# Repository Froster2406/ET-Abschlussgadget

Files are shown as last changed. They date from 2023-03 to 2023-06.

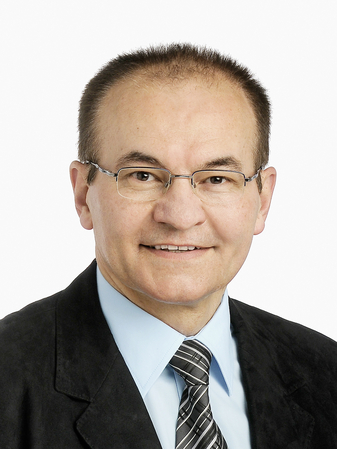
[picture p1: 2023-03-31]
Hardware/UrsRoethlisberger.jpeg

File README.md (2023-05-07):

# HS20-23 ET Abschlussgadget

Als Teil der Abschlusszeitung gibt es auch dieses Jahr wieder ein kleines Gadget kostenfrei dazu. Ganz im Namen des Überthemas "ET im PRENpunkt" mit der Anlehung an "Familien im Brennpunkt", kannst auch Du herausfinden, wie viel ET in Dir steckt. Aber nur wenn Du so asozial wie ein ET'ler bist, schaltet sich die geheime Zusatzfunktion frei.

## Verwendung

* Beiligende Batterie einlegen
* Schalter auf Platine in ON-Zustand versetzten
* Finger auf "Drück mich!" legen
* Anzeige ablesen

<details>
<summary>only for real engineers</summary>
<br>
You deem yourself a true engineer? Great!<br>
Tag along as we dive deeper into how you can reprogram the microcontroller. <br>

## general information
* [Reference Manual](https://ww1.microchip.com/downloads/aemDocuments/documents/MCU08/ProductDocuments/DataSheets/ATtiny212-214-412-414-416-DataSheet-DS40002287A.pdf)
* There are two pins (J1 & J2) on the side of the PCB than can be freely addressed, without interfering with the main functionality of the board

## preresquisites
* USB to serial converter | USB to TTL converter <br>
`Any converter (3.3V or 5V) off of Aliexpress, Ebay, Mouser, etc. will do.`
* 1kOhm resistor <br>
* Wires to connect the PCB to the converter <br>
* [Microchip Studio](https://www.microchip.com/en-us/tools-resources/develop/microchip-studio) <br>
* [Python](https://www.python.org/downloads/) installed on your machine <br>
* Python package: [pymcuprog](https://pypi.org/project/pymcuprog/) <br>
`pip install pymcuprog`<br>

## wiring diagram 
https://github.com/microchip-pic-avr-tools/pymcuprog#serial-port-updi-pyupdi

## reprogramming
* Connect the PCB to the USB to serial converter according to the wiring diagram
* Adjust the code to your liking and build it with F7
* Navigate to the python-programmer script <br>
`cd <YOUR_PATH>\ET-Abschlussgadget\Software\Programmer Python`
* Run the programming command <br>
`python attiny414.py <COM_PORT> <ABSOLUTE_PATH_TO_HEX_FILE_YOU_COMPILED_WITH_MICROCHIP_STUDIO>` <br>
*COM_PORT: If unknown, the available ones will be printed in the console*

* Power cycle the PCB

</details>

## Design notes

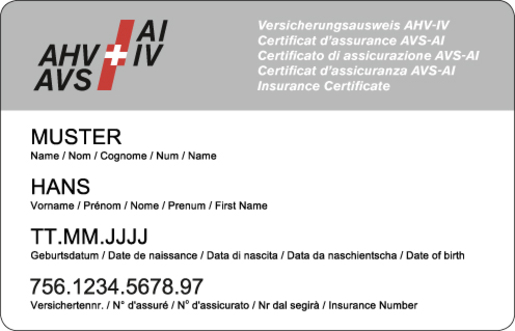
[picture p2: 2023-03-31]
Hardware/AHVAusweisMuster.jpg

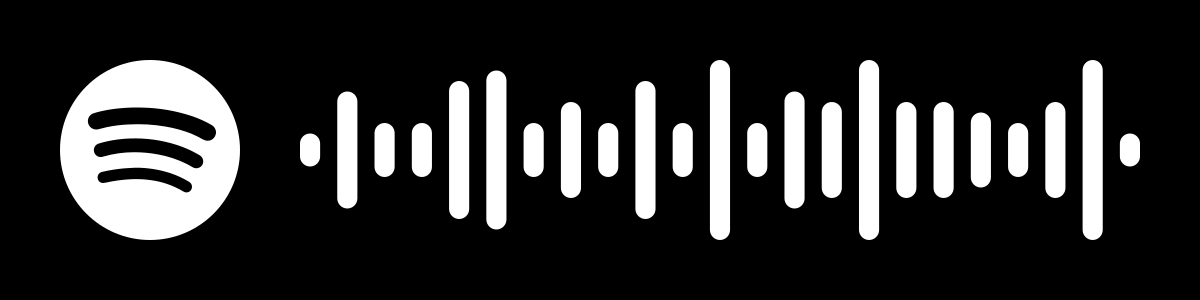
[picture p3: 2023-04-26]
Hardware/Spotify_Code.png

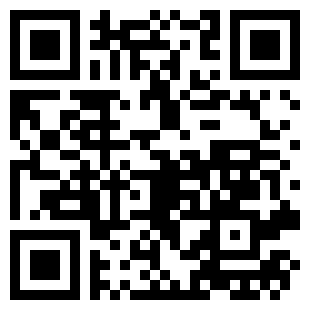
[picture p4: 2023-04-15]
Hardware/QR_Repo.png

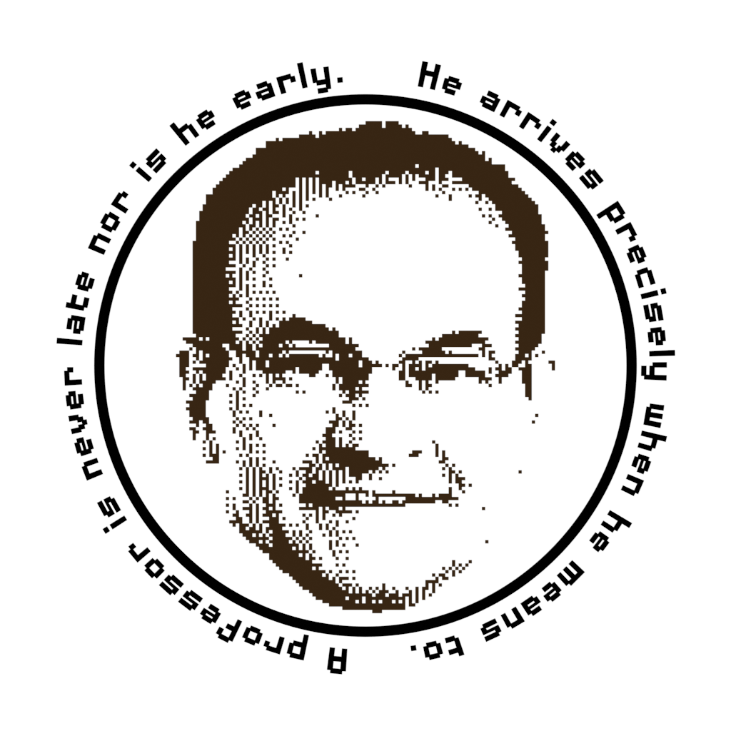
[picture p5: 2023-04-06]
Hardware/Rothli_Sticker_1.png

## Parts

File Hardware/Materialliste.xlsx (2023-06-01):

Typ | Link
MCU | https://www.lcsc.com/product-detail/Microcontroller-Units-MCUs-MPUs-SOCs_Microchip-Tech-ATTINY414-SSNR_C189365.html
CR2032 Battery holder | https://www.lcsc.com/product-detail/span-style-background-color-ff0-Battery-span-Connectors_Q-J-C70373_C70373.html
IR LED | https://www.lcsc.com/product-detail/Infrared-IR-LEDs_XSSY-XS-IR04A05-802_C5205266.html
LED Rot | https://www.lcsc.com/product-detail/Light-Emitting-Diodes-span-style-background-color-ff0-LED-span_XINGLIGHT-XL-1608SURC-06_C965799.html
Switch | https://www.lcsc.com/product-detail/span-style-background-color-ff0-Slide-span-Switches_SHOU-HAN-MSK12CO2-SZ_C2681568.html
100nF Cap | https://www.lcsc.com/product-detail/Multilayer-Ceramic-Capacitors-MLCC-SMD-SMT_CCTC-TCC0603X7R104K500CT_C282519.html
560 Ohm Resistor | https://www.lcsc.com/product-detail/Chip-Resistor-Surface-Mount_UNI-ROYAL-Uniroyal-Elec-0603WAJ0561T5E_C25247.html
N-MOSFET | https://www.lcsc.com/product-detail/MOSFETs_YONGYUTAI-SI2302_C2891732.html
1M Ohm Resistor | https://www.lcsc.com/product-detail/Chip-Resistor-Surface-Mount_Sunway-SC0603F1004F2BNRH_C3152128.html

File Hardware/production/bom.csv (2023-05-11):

Designator | Footprint | Quantity | Value | LCSC Part #
BT1 | BAT-SMD_CR2032-3V | 1 | 3V | C70373
C1 | C0603 | 1 | 100nF | C38141
D1 | XS-IR04A05-802 | 1 | LED_Ir | C396649
D2, D3, D4, D5, D6 | LED0603-RD_RED | 5 | LED_Red | C965799
J1, J2 | TestPoint_Pad_D2.0mm | 2 | EXTCLK
J3 | TestPoint_Pad_D1.0mm | 1 | PB0
J4 | TestPoint_Pad_D1.0mm | 1 | PB1
J5 | TestPoint_Pad_D2.0mm | 1 | UPDI / RESET
Q2 | SOT-23-3_L2.9-W1.3-P1.90-LS2.4-BR | 1 | SI2302_C2891732 | C2891732
R2, R3, R4, R5, R6, R7 | 0603 | 6 | 560 | C5140946
R8 | 0603 | 1 | 1M | C5140946
SW1 | SW-TH_MSK12C02 | 1 | ON/OFF | C2681568
TP1 | TestPoint_Pad_4.0x4.0mm | 1 | Capacitive Pad
U1 | SOIC-14_L8.7-W3.9-P1.27-LS6.0-BL | 1 | ATtiny414-SS | C189365

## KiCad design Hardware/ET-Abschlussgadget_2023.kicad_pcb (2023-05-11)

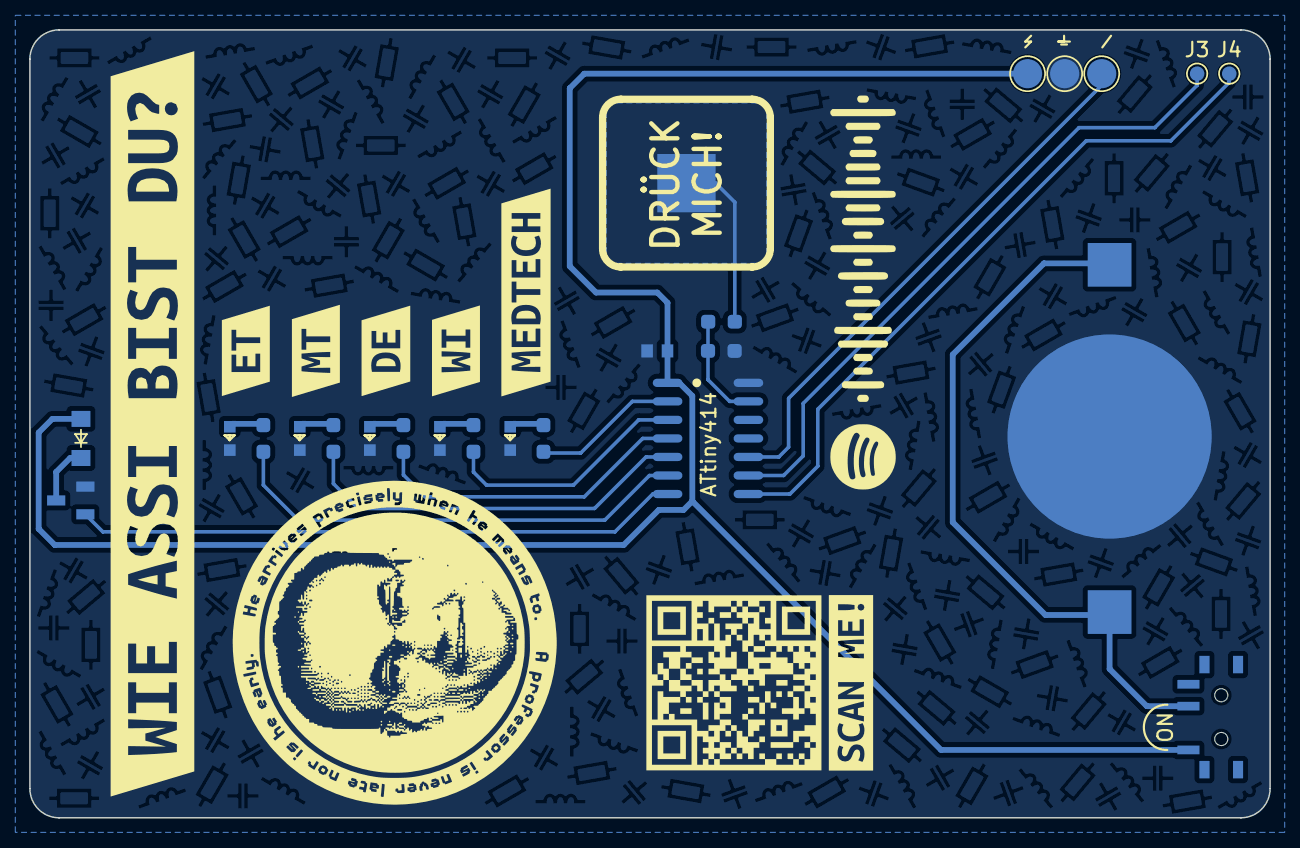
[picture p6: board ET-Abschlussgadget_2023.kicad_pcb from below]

Board: 2 copper layers, 85.0 x 54.0 mm, 31 parts (31 on the bottom side), 20 nets.

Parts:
BT1: 3V; BAT-SMD_CR2032-3V
C1: 100nF; C0603
D1: LED_Ir; XS-IR04A05-802
D2, D3, D4, D5, D6: LED_Red; LED0603-RD_RED
J1, J2: EXTCLK; TestPoint_Pad_D2.0mm
J3: PB0; TestPoint_Pad_D1.0mm
J4: PB1; TestPoint_Pad_D1.0mm
J5: UPDI / RESET; TestPoint_Pad_D2.0mm
Q2: SI2302_C2891732; SOT-23-3_L2.9-W1.3-P1.90-LS2.4-BR
R2, R3, R4, R5, R6, R7: 560; R_0603_1608Metric_Pad0.98x0.95mm_HandSolder
R8: 1M; R_0603_1608Metric_Pad0.98x0.95mm_HandSolder
SW1: ON/OFF; SW-TH_MSK12C02
TP1: Capacitive Pad; TestPoint_Pad_4.0x4.0mm
U1: ATtiny414-SS; SOIC-14_L8.7-W3.9-P1.27-LS6.0-BL
kibuzzard-642F12C7: G***; kibuzzard-642F12C7
kibuzzard-642F12D5: G***; kibuzzard-642F12D5
kibuzzard-642F12E3: G***; kibuzzard-642F12E3
kibuzzard-642F12EF: G***; kibuzzard-642F12EF
kibuzzard-642F1274: G***; kibuzzard-642F1274
kibuzzard-642F1300: G***; kibuzzard-642F1300
kibuzzard-64480F6A: G***; kibuzzard-64480F6A

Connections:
/Cap_Pad: R5.2, TP1.1
/Cap_Pad / ADC1: R5.1, R8.2, U1.13 (PA3)
/LED 1: R2.2, U1.6 (PB3)
/LED 2: R3.1, U1.5 (PA7)
/LED 3: R4.1, U1.4 (PA6)
/LED 4: R6.2, U1.3 (PA5)
/LED 5: R7.2, U1.2 (PA4)
/LED IR: Q2.1 (G), U1.7 (PB2)
/UPDI / RESET: J5.1, U1.10 (~RESET/PA0)
GND: BT1.2 (-), C1.2, D2.1 (K), D3.1 (K), D4.1 (K), D5.1 (K), D6.1 (K), J2.1, Q2.2 (S), R8.1, U1.14 (GND)
unnamed: BT1.1 (+), SW1.2 (B)
unnamed: D1.1 (K), Q2.3 (D)
unnamed: D2.2 (A), R2.1
unnamed: D3.2 (A), R3.2
unnamed: D4.2 (A), R4.2
unnamed: D5.2 (A), R6.1
unnamed: D6.2 (A), R7.1
unnamed: J3.1, U1.9 (PB0)
unnamed: J4.1, U1.8 (PB1)
VCC: C1.1, D1.2 (A), J1.1, SW1.1 (A), U1.1 (VCC)

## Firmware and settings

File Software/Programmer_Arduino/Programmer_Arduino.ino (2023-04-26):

/**************************************************
 * TPI programmer for ATtiny10
 * (possibly 4,5,9 as well)
 * Make the connections as shown below.
 * 
 * To use:
 *  - Upload to arduino and power off
 *  - Connect ATtiny10 as shown
 *  - Power on and open the serial monitor
 *  - If things are working so far you should
 *    see "NVM enabled" and "ATtiny10 connected".
 *  - Input one-letter commands via serial monitor:
 *    D = dump memory. Displays all current memory
 *        on the chip
 *    E = erase chip. Erases all program memory
 *    R = read program. After sending this command
 *        you have 20 seconds to copy and paste the
 *        entire contents of a .hex file into the
 *        serial monitor and send. You can do the
 *        whole file at once. If it was successful,
 *        you should see "program received".
 *    P = write program. After reading the program
 *        with the R command, use this to write the
 *        program to the ATtiny10.
 *    V = verify. Verifies that the program was
 *        written correctly. If not, it will display
 *        the errors.
 *    F = finish. not necessary, but this disables
 *        further access until the arduino is reset
 *    S = set fuse. follow the instructions to set
 *        one of the three fuses.
 *    C = clear fuse. follow the instructions to clear
 *        one of the three fuses.
 *  - Finally, power off the arduino and remove the
 *    Attiny10
 *                                                *
 * Arduino                 ATtiny10               *
 * ----------+          +----------------         *
 * (SS#)  10 |--[R]-----| 6 (RESET#/PB3)          *
 *           |          |                         *     
 * (MOSI) 16 |--[R]--+--| 1 (TPIDATA/PB0)         *
 *           |       |  |                         *
 * (MISO) 14 |--[R]--+  |                         *
 *           |          |                         *     
 * (SCK)  15 |--[R]-----| 3 (TPICLK/PB1)          *
 * ----------+          +----------------         *
 *                                                *
 *  -[R]-  =  a few kOhm resistor                 *
 *                                                *
 *  this picture : 2011/12/08 by pcm1723          *
 *                                                *
 * thanks to pcm1723 for tpitest.pde upon which   *
 * this is based                                  *
 **************************************************/
  
#include <SPI.h>
#include "pins_arduino.h"

#define SS 10

// define the instruction set bytes
#define SLD    0x20
#define SLDp   0x24
#define SST    0x60
#define SSTp   0x64
#define SSTPRH 0x69
#define SSTPRL 0x68
// see functions below ////////////////////////////////
// SIN  0b0aa1aaaa replace a with 6 address bits   
// SOUT 0b1aa1aaaa replace a with 6 address bits 
// SLDCS  0b1000aaaa replace a with address bits 
// SSTCS  0b1100aaaa replace a with address bits 
///////////////////////////////////////////////////////
#define SKEY   0xE0
#define NVM_PROGRAM_ENABLE 0x1289AB45CDD888FFULL // the ULL means unsigned long long

#define NVMCMD 0x33
#define NVMCSR 0x32
#define NVM_NOP 0x00
#define NVM_CHIP_ERASE 0x10
#define NVM_SECTION_ERASE 0x14
#define NVM_WORD_WRITE 0x1D

// represents the current pointer register value
unsigned short adrs = 0x0000;

// used for storing a program file
uint8_t data[1024]; //program data
unsigned int progSize = 0; //program size in bytes

// used for various purposes
long startTime;
int timeout;
uint8_t b, b1, b2, b3;
boolean idChecked;

void setup(){
  pinMode(SS, OUTPUT);
  digitalWrite(SS, HIGH);
  
  // set up serial
  Serial.begin(115200); // you can change this if you want
  while(!Serial);
  Serial.println("Start");
  Serial.print("SS: ");
  Serial.println(SS);
  Serial.print("MOSI: ");
  Serial.println(MOSI);
  Serial.print("MISO: ");
  Serial.println(MISO);
  Serial.print("SCK: ");
  Serial.println(SCK);
  pinMode(SS, OUTPUT);
  pinMode(MOSI, OUTPUT);
  pinMode(SCK, OUTPUT);
  
  // set up SPI
  SPI.begin();
  SPI.setBitOrder(LSBFIRST);
  SPI.setDataMode(SPI_MODE0);
  SPI.setClockDivider(SPI_CLOCK_DIV32);
  
  // enter TPI programming mode
  digitalWrite(SS, LOW); // assert RESET on tiny
  delay(1); // t_RST min = 400 ns @ Vcc = 5 V
  
  SPI.transfer(0xff); // activate TPI by emitting
  SPI.transfer(0xff); // 16 or more pulses on TPICLK
  SPI.transfer(0xff); // while holding TPIDATA to "1"
  
  writeCSS(0x02, 0x04); // TPIPCR, guard time = 8bits (default=128)

  Serial.println("CSS");
  
  send_skey(NVM_PROGRAM_ENABLE); // enable NVM interface
  
  Serial.println("SKEY");
  // wait for NVM to be enabled
  /*while(1) {
    SPI.transfer(0x55);
  }*/
  
  while((readCSS(0x00) & 0x02) < 1){
    Serial.print(".");
  }
  Serial.println("NVM enabled");
  
  // initialize memory pointer register  
  setPointer(0x0000);
  
  timeout = 20000;
  idChecked = false;
} // end setup()

void loop(){
  if(!idChecked){
    checkID();
    idChecked = true;
  }
  // when ready, send ready signal '.' and wait
  //Serial.write('.');
  while(Serial.available() < 1){
    // wait
  }
  // the first byte is a command
  // 'R' = read program via serial onto the arduino
  // 'P' = program the ATtiny using the read program
  // 'V' = verify the program on the ATtiny
  // 'D' = dump memory to serial monitor
  // 'E' = erase chip. erases current program memory.(done automatically by 'P')
  // 'F' = finalize. Just disables NVM. Not necessary.
  // 'S' = set fuse
  // 'C' = clear fuse
  
  char comnd = Serial.read();
  if(comnd == 'D'){
    dumpMemory();
  }else if(comnd == 'R'){
    Serial.println("Paste hex contents");
    if(receiveProgram()){
      Serial.println("program received");
      delay(10);
      Serial.print("size: ");
      Serial.print(progSize);
      Serial.println("bytes");
    }
  }else if(comnd == 'P'){
    if(progSize > 0){
      writeProgram();
    }else{
      Serial.println("no program data read");
    }
  }else if(comnd == 'E'){
    eraseChip();
  }else if(comnd == 'V'){
    if(verifyProgram()){
      Serial.println("program verified: correct");
    }
  }else if(comnd == 'F'){
    finish();
    Serial.println("everything finished. unplug and disconnect wires");
    return;
  }else if(comnd == 'S'){
    setConfig(true);
  }else if(comnd == 'C'){
    setConfig(false);
  }else{
    Serial.println("received unknown command");
  }
}

//  print the register, SRAM, config and signature memory
void dumpMemory(){
  uint8_t i;
  // initialize memory pointer register 
  setPointer(0x0000);
  
  Serial.println("Current memory state:");
  // read the memory up to 0x4400
  while(adrs < 0x4400){
    // read the byte at the current pointer address
    // and increment address
    tpi_send_byte(SLDp);
    b = tpi_receive_byte(); // get data byte
    
    // read all the memory, but only print
    // the register, SRAM, config and signature memory
    if ((0x0000 <= adrs && adrs <= 0x005F) // register/SRAM
       |(0x3F00 <= adrs && adrs <= 0x3F01) // NVM lock bits
       |(0x3F40 <= adrs && adrs <= 0x3F41) // config
       |(0x3F80 <= adrs && adrs <= 0x3F81) // calibration
       |(0x3FC0 <= adrs && adrs <= 0x3FC3) // ID
       |(0x4000 <= adrs && adrs <= 0x43FF) ) { // program
      // print +number along the top
      if ((0x00 == adrs)
          |(0x3f00 == adrs) // NVM lock bits
          |(0x3F40 == adrs) // config
          |(0x3F80 == adrs) // calibration
          |(0x3FC0 == adrs) // ID
          |(0x4000 == adrs) ) {
        outNewline(); 
        if(adrs == 0x0000){ Serial.print("registers, SRAM"); }
        if(adrs == 0x3F00){ Serial.print("NVM lock"); }
        if(adrs == 0x3F40){ Serial.print("configuration"); }
        if(adrs == 0x3F80){ Serial.print("calibration"); }
        if(adrs == 0x3FC0){ Serial.print("device ID"); }
        if(adrs == 0x4000){ Serial.print("program"); }
        outNewline();
        for (i = 0; i < 5; i++) { outChar(' '); }
        for (i = 0; i < 16; i++) {
          outChar(' '); outChar('+');
          outHex1(i);
        }
      }
      // print number on the left
      if (0 == (0x000f & adrs)) {
        outNewline();
        outHex4(adrs); // print address in hex 4 digits
        outChar(':'); // delimiter
      }
      outChar(' '); // delimiter
      outHex2(b); // print data in hex 2 digits 
    }
    adrs++; // increment memory address
    if(adrs == 0x0060){
      // skip reserved memory
      setPointer(0x3F00);
    }
  }
  Serial.println(" ");
} // end dumpMemory()

// receive and translate the contents of a hex file
// The maximum program size is 1024 bytes, so this should all fit in SRAM
boolean receiveProgram(){
  char datlength[] = "00";
  char addr[] = "0000";
  char something[] = "00";
  char chksm[] = "00";
  unsigned int currentByte = 0;
  progSize = 0;
  uint8_t linelength = 0;
  boolean fileEnd = false;
  
  // read in the data and 
  while(!fileEnd){
    startTime = millis();
    while(Serial.available() < 10){
      //Serial.println(Serial.available());
      if(millis()-startTime > timeout){ 
        Serial.println("couldn't receive data:");
        Serial.println("timed out");
        return false; 
      }
    }
    if(Serial.read() != ':'){ // maybe it was a newline??
      if(Serial.read() != ':'){
        Serial.println("couldn't receive data:");
        Serial.println("hex file format error");
        return false; 
      }
    }
    // read data length
    datlength[0] = Serial.read();
    datlength[1] = Serial.read();
    linelength = byteval(datlength[0], datlength[1]);
    
    // read address. if "0000" currentByte = 0
    addr[0] = Serial.read();
    addr[1] = Serial.read();
    addr[2] = Serial.read();
    addr[3] = Serial.read();
    if(linelength != 0x00 && addr[0]=='0' && addr[1]=='0' && addr[2]=='0' && addr[3]=='0'){ currentByte = 0; }
    
    // read type thingy. "01" means end of file
    something[0] = Serial.read();
    something[1] = Serial.read();
    if(something[1] == '1'){
      fileEnd = true;
    }
    
    // read in the data 
    for(int k=0; k<linelength; k++){
      if(currentByte == 1024){
        Serial.println("couldn't receive data:");
        Serial.println("program is too large");
        return false;
      }
      startTime = millis();
      while(Serial.available() < 2){
        if(millis()-startTime > timeout){ 
          Serial.println("couldn't receive data:");
          Serial.println("timed out");
          return false; 
        }
      }
      data[currentByte] = byteval(Serial.read(), Serial.read());
      currentByte++;
    }
    
    // read in the checksum.
    startTime = millis();
    while(Serial.available() < 2){
      if(millis()-startTime > timeout){ 
        Serial.println("couldn't receive data:");
        Serial.println("timed out");
        return false; 
      }
    }
    chksm[0] = Serial.read();
    chksm[1] = Serial.read();
    
  }
  progSize = currentByte;
  // we need an even number of bytes for word writing
  if(progSize & 0x0001){
    data[progSize] = 0x00;
    progSize++;
  }
  
  // the program was successfully read
  return true;
}

// write the data[] to program memory
void writeProgram(){
  if(progSize < 1){
    Serial.println("program size is 0??");
    return;
  }
  
  // erase the chip
  eraseChip();
  
  setPointer(0x4000);
  adrs = 0x4000;
  writeIO(NVMCMD, NVM_WORD_WRITE);
  
  // now write all the bytes to program memory
  // write two bytes at a time (a word) and wait
  for(int k=0; k<progSize-1; k=k+2){
    tpi_send_byte(SSTp);
    tpi_send_byte(data[k]); // LSB first
    tpi_send_byte(SSTp);
    tpi_send_byte(data[k+1]); // then MSB
    while((readIO(NVMCSR) & (1<<7)) != 0x00){
      // wait for write to finish
    }
  }
  
  writeIO(NVMCMD, NVM_NOP);
  SPI.transfer(0xff);
  SPI.transfer(0xff);
  
  Serial.print("Wrote program: ");
  Serial.print(progSize, DEC);
  Serial.println(" of 1024 bytes");
}

void eraseChip(){
  // initialize memory pointer register 
  setPointer(0x4001); // need the +1 for chip erase
  
  // erase the chip
  writeIO(NVMCMD, NVM_CHIP_ERASE);
  tpi_send_byte(SSTp);
  tpi_send_byte(0xAA);
  tpi_send_byte(SSTp);
  tpi_send_byte(0xAA);
  tpi_send_byte(SSTp);
  tpi_send_byte(0xAA);
  tpi_send_byte(SSTp);
  tpi_send_byte(0xAA);
  while((readIO(NVMCSR) & (1<<7)) != 0x00){
    // wait for erasing to finish
  }
  Serial.println("chip erased");
}

boolean verifyProgram(){
  if(progSize < 1){
    Serial.println("program size is 0??");
    return false;
  }
  
  boolean correct = true;
  unsigned short ind = 0;
  setPointer(0x4000);
  while(ind < progSize){
    tpi_send_byte(SLDp);
    b = tpi_receive_byte(); // get data byte
    
    if(b != data[ind]){
      correct = false;
      Serial.println("program error:");
      Serial.print("byte ");
      outHex4(ind);
      Serial.print(" expected ");
      outHex2(data[ind]);
      Serial.print(" read ");
      outHex2(b);
      outNewline();
    }
    ind++;
  }
  return correct;
}

void setConfig(boolean val){
  // get current config byte
  setPointer(0x3F40);
  tpi_send_byte(SLD);
  b = tpi_receive_byte();
  
  Serial.println("input one of these letters");
  Serial.println("c = system clock output");
  Serial.println("w = watchdog timer on");
  Serial.println("r = disable reset");
  Serial.println("x = cancel. don't change anything");
  
  while(Serial.available() < 1){
    // wait
  }
  char comnd = Serial.read();
  setPointer(0x3F40);
  writeIO(NVMCMD, (val ? NVM_WORD_WRITE : NVM_SECTION_ERASE) );
  
  if(comnd == 'c'){
    tpi_send_byte(SSTp);
	if(val){
	  tpi_send_byte(b & 0b11111011);
    }else{
      tpi_send_byte(b | 0x04);
    }
	tpi_send_byte(SSTp);
	tpi_send_byte(0xFF);
  }else if(comnd == 'w'){
    tpi_send_byte(SSTp);
	if(val){
	  tpi_send_byte(b & 0b11111101);
    }else{
      tpi_send_byte(b | 0x02);
    }
	tpi_send_byte(SSTp);
	tpi_send_byte(0xFF);
  }else if(comnd == 'r'){
    tpi_send_byte(SSTp);
	if(val){
	  tpi_send_byte(b & 0b11111110);
    }else{
      tpi_send_byte(b | 0x01);
    }
	tpi_send_byte(SSTp);
	tpi_send_byte(0xFF);
  }else if(comnd == 'x'){
    // do nothing
  }else{
    Serial.println("received unknown command. cancelling");
  }
  while((readIO(NVMCSR) & (1<<7)) != 0x00){
    // wait for write to finish
  }
  writeIO(NVMCMD, NVM_NOP);
  SPI.transfer(0xff);
  SPI.transfer(0xff);
}


void finish(){
  writeCSS(0x00, 0x00);
  SPI.transfer(0xff);
  SPI.transfer(0xff);
  digitalWrite(SS, HIGH); // release RESET
  delay(1); // t_RST min = 400 ns @ Vcc = 5 V
  pinMode(SS, INPUT);
  pinMode(MOSI, INPUT);
  pinMode(MISO, INPUT);
  pinMode(SCK, INPUT);
}

void checkID(){
  // check the device ID
  uint8_t id1, id2, id3;
  setPointer(0x3FC0);
  
  tpi_send_byte(SLDp);
  id1 = tpi_receive_byte();
  tpi_send_byte(SLDp);
  id2 = tpi_receive_byte();
  tpi_send_byte(SLDp);
  id3 = tpi_receive_byte();
  if(id1==0x1E && id2==0x90 && id3==0x03){
    Serial.println("ATtiny10 connected");
  }else{
    Serial.println("Unknown chip connected!!");
  }
}

/* 
* send a byte in one TPI frame (12 bits)
* (1 start + 8 data + 1 parity + 2 stop)
* using 2 SPI data bytes (2 x 8 = 16 clocks)
* (with 4 extra idle bits)
*/
void tpi_send_byte( uint8_t data ){
  // compute partiy bit
  uint8_t par = data;
  par ^= (par >> 4); // b[7:4] (+) b[3:0]
  par ^= (par >> 2); // b[3:2] (+) b[1:0]
  par ^= (par >> 1); // b[1] (+) b[0]
  
  // REMEMBER: this is in LSBfirst mode and idle is high
  // (2 idle) + (1 start bit) + (data[4:0])
  SPI.transfer(0x03 | (data << 3));
  // (data[7:5]) + (1 parity) + (2 stop bits) + (2 idle)
  SPI.transfer(0xf0 | (par << 3) | (data >> 5));
} // end tpi_send_byte()

/*
* receive TPI 12-bit format byte data
* via SPI 2 bytes (16 clocks) or 3 bytes (24 clocks)
*/
uint8_t tpi_receive_byte( void ){
  //uint8_t b1, b2, b3;
  // keep transmitting high(idle) while waiting for a start bit
  do {
    b1 = SPI.transfer(0xff);
  } while (0xff == b1);
  // get (partial) data bits
  b2 = SPI.transfer(0xff);
  // if the first byte(b1) contains less than 4 data bits
  // we need to get a third byte to get the parity and stop bits
  if (0x0f == (0x0f & b1)) { 
    b3 = SPI.transfer(0xff);
  }
  
  // now shift the bits into the right positions
  // b1 should hold only idle and start bits = 0b01111111
  while (0x7f != b1) { // data not aligned
    b2 <<= 1; // shift left data bits
    if (0x80 & b1) { // carry from 1st byte
      b2 |= 1; // set bit
    }
    b1 <<= 1;
    b1 |= 0x01; // fill with idle bit (1)
  }
  // now the data byte is stored in b2
  return( b2 );
} // end tpi_receive_byte()

// send the 64 bit NVM key
void send_skey(uint64_t nvm_key){
  tpi_send_byte(SKEY);
  while(nvm_key){
    tpi_send_byte(nvm_key & 0xFF);
    nvm_key >>= 8;
  }
} // end send_skey()

// sets the pointer address
void setPointer(unsigned short address){
  adrs = address;
  tpi_send_byte(SSTPRL);
  tpi_send_byte(address & 0xff);
  tpi_send_byte(SSTPRH);
  tpi_send_byte((address>>8) & 0xff);
}

// writes using SOUT
void writeIO(uint8_t address, uint8_t value){
  //  SOUT 0b1aa1aaaa replace a with 6 address bits 
  tpi_send_byte(0x90 | (address & 0x0F) | ((address & 0x30) << 1));
  tpi_send_byte(value);
}

// reads using SIN
uint8_t readIO(uint8_t address){
  //  SIN 0b0aa1aaaa replace a with 6 address bits 
  tpi_send_byte(0x10 | (address & 0x0F) | ((address & 0x30) << 1));
  return tpi_receive_byte();
}

// writes to CSS
void writeCSS(uint8_t address, uint8_t value){
  tpi_send_byte(0xC0 | address);
  tpi_send_byte(value);
}

// reads from CSS
uint8_t readCSS(uint8_t address){
  tpi_send_byte(0x80 | address);
  return tpi_receive_byte();
}

// converts two chars to one byte
// c1 is MS, c2 is LS
uint8_t byteval(char c1, char c2){
  uint8_t by;
  if(c1 <= '9'){
    by = c1-'0';
  }else{
    by = c1-'A'+10;
  }
  by = by << 4;
  if(c2 <= '9'){
    by += c2-'0';
  }else{
    by += c2-'A'+10;
  }
  return by;
}

/*
* The following were used by tpitest.pde
*/
void outChar( char c ){
  Serial.print(c);  
}

void outNewline( void ){
  Serial.println();  
}

 void outHex1(uint8_t n){
  Serial.print(0x0f & n, HEX);  
}

void outHex2(uint8_t n){
  outHex1(n >> 4); outHex1(n);
}

void outHex4(uint16_t n){
  outHex2(n >> 8); outHex2(n);
}

// end of file

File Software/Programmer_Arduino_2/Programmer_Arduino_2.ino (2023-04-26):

/**************************************************
 * TPI programmer for ATtiny4/5/9/10/20/40
 *
 * Make the connections as shown below.
 *
 * To use:
 ***** Buad rate must be set to 9600 ****
 *
 *  - Upload to arduino and power off
 *  - Connect ATtiny10 as shown
 *  - Power on and open the serial monitor
 *  - If things are working so far you should
 *    see "NVM enabled" and "ATtiny10/20/40 connected".
 *  - Input one-letter commands via serial monitor:
 *
 *    D = dump memory. Displays all current memory
 *        on the chip
 *
 *    E = erase chip. Erases all program memory
 *        automatically done at time of programming
 *
 *    P = write program. After sending this, paste
 *        the program from the hex file into the
 *        serial monitor.
 *
 *    S = set fuse. follow the instructions to set
 *        one of the three fuses.
 *
 *    C = clear fuse. follow the instructions to clear
 *        one of the three fuses.
 *
 *    H = Toggle High Voltage Programming  
 *
 *    T = Toggle +12v enabled by High, or Low
 *
 *    R/r = Quick reset
 *
 *  - Finally, power off the arduino and remove the
 *    Attiny10/20/40
 *
 *
 * Arduino                 ATtiny10               *
 * ----------+          +----------------         *
 * (SS#)  10 |--[R]-----| 6 (RESET#/PB3)          *
 *           |          |                         *
 * (MOSI) 11 |--[R]--+--| 1 (TPIDATA/PB0)         *
 *           |       |  |                         *
 * (MISO) 12 |--[R]--+  |                         *
 *           |          |                         *
 * (SCK)  13 |--[R]-----| 3 (TPICLK/PB1)          *
 * ----------+          +----------------         *
 *                                                *
 * ----------+          +----------------         *
 * (HVP)   9 |---       | 6 (RESET#/PB3)          *
 *           |          |                         *
 *                                                *
 *  -[R]-  =  a 220 - 1K Ohm resistor             *
 *                                                *
 *  this picture : 2011/12/08 by pcm1723          *
 *  modified :2015/02/27 by KD                    *
 *                                                *
 * thanks to pcm1723 for tpitest.pde upon which   *
 * this is based                                  *
 **************************************************
 Updates:
   Dec 04, 2017: thejamestate@gmail.com
       * Added support for ATtiny102 and ATtiny104
   Jan 23, 2017: Ksdsksd@gmail.com
                * Thanks to InoueTaichi Fixed incorrect #define Tiny40 
                
   Mar 05, 2015: Ksdsksd@gamil.com
                * Added notifications to setting and clearing the system flags.
 
   Feb 23, 2015: Ksdsksd@gamil.com
                * Changed the programmer Diagram, This is the config I use, and get a sucessful programming of a tiny10 at 9600 baud.
                
   Mar 22, 2014: Ksdsksd@gmail.com
                * Added the quick reset to high before resetting the device.
                * Added code to stop the SPI and float the pins for testing the device while connected.
   Mar 20, 2014: Ksdsksd@gmail.com
                * Added a quick reset by sending 'r' or 'R' via the serial monitor.
                * Added a High voltage programming option from pin 9, toggled by 'H'
                * Added a High/low option for providing 12v to the reset pin, toggled by 'T'
   Mar 17, 2014: Ksdsksd@gmail.com
                * Had some trouble with the nibbles being swapped when programming on the 10 & 20,
                  added b1,b2 to hold the serial data before calling byteval()
                * Added Nat Blundell's patch to the code
   Apr 10, 2013: Ksdsksd@gmail.com
                * Applied Fix for setting and clearing flags
   Feb 7,  2013: Ksdsksd@gmail.com
                * Fixed programming timer, had intitial start at zero instead of current time.
   Dec 11, 2012: Ksdsksd@gmail.com
                * Added detect and programming for 4/5/9
   Dec 5-6, 2012: Ksdsksd@gmail.com
                * Incorperated read, and verify into program. Now have no program size limitation by using 328p.
                * Changed the outHex routines consolidated them into 1, number to be printed, and number of nibbles
                * Added a type check to distinguish between Tiny10/20/40
                * Added an auto word size check to ensure that there is the proper amount of words written for a 10/20/40
                * Removed Read program, Verify, and Finish from options
                * Changed baud rate to 19200 for delay from data written to the chip, to prevent serial buffer overrun.
   Oct 5, 2012: Ksdsksd@gmail.com
                *** Noticed that when programming, the verification fails
                    at times by last 1-2 bytes programmed, and the Tiny would act erratic.
                    Quick fix was adding 3 NOP's to the end the Tiny's code, and ignoring the errors, the Tiny then performed as expected.
   Oct 4, 2012: Ksdsksd@gmail.com
                * Moved all Serial printed strings to program space
                * Added code to detect Tiny20
*/

#define SS 10
#define MOSI 16
#define MISO 14
#define SCK 15

#include <SPI.h>
#include "pins_arduino.h"

// define the instruction set bytes
#define SLD    0x20
#define SLDp   0x24
#define SST    0x60
#define SSTp   0x64
#define SSTPRH 0x69
#define SSTPRL 0x68
// see functions below ////////////////////////////////
// SIN  0b0aa1aaaa replace a with 6 address bits
// SOUT 0b1aa1aaaa replace a with 6 address bits
// SLDCS  0b1000aaaa replace a with address bits
// SSTCS  0b1100aaaa replace a with address bits
///////////////////////////////////////////////////////
#define SKEY   0xE0
#define NVM_PROGRAM_ENABLE 0x1289AB45CDD888FFULL // the ULL means unsigned long long

#define NVMCMD 0x33
#define NVMCSR 0x32
#define NVM_NOP 0x00
#define NVM_CHIP_ERASE 0x10
#define NVM_SECTION_ERASE 0x14
#define NVM_WORD_WRITE 0x1D

#define HVReset 9

#define Tiny4_5 10
#define Tiny9 1
#define Tiny10 1
#define Tiny20 2
#define Tiny40 4
#define Tiny102 1
#define Tiny104 1

#define TimeOut 1
#define HexError 2
#define TooLarge 3
// represents the current pointer register value
unsigned short adrs = 0x0000;

// used for storing a program file
uint8_t data[16]; //program data
unsigned int progSize = 0; //program size in bytes

// used for various purposes
long startTime;
int timeout;
uint8_t b, b1, b2, b3;
boolean idChecked;
boolean correct;
char type; // type of chip connected 1 = Tiny10, 2 = Tiny20
char HVP = 0;
char HVON = 0;

int counti = 0;
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

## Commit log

2023-03-31 Added front silk screen
    [ET-Abschlussgadget_2023.kicad_pcb]
2023-03-31 Add rounded corners
    [ET-Abschlussgadget_2023.kicad_pcb]
2023-03-31 Add kicad backup directory to gitignore
2023-04-01 Added first & last name
    [ET-Abschlussgadget_2023.kicad_pcb]
2023-04-06 Add schematic
    [ET-Abschlussgadget_2023.kicad_sch]
2023-04-06 Add basic layout
    [ET-Abschlussgadget_2023.kicad_pcb, ET-Abschlussgadget_2023.kicad_sch]
2023-04-06 Add testpoints, bottom silkscreen, rothli
    [ET-Abschlussgadget_2023.kicad_pcb, ET-Abschlussgadget_2023.kicad_sch]
2023-04-06 Fix silkscreen and solder mask
    [ET-Abschlussgadget_2023.kicad_pcb]
2023-04-06 Improve component and silkscreen placement
    [ET-Abschlussgadget_2023.kicad_pcb, ET-Abschlussgadget_2023.kicad_sch]
2023-04-06 Improve silkscreen
    [ET-Abschlussgadget_2023.kicad_pcb]
2023-04-06 Add inverted banner
    [ET-Abschlussgadget_2023.kicad_pcb]
2023-04-07 Add series resistor to capacitive pad
    [ET-Abschlussgadget_2023.kicad_pcb, ET-Abschlussgadget_2023.kicad_sch]
2023-04-07 Add bypass capacitor
    [ET-Abschlussgadget_2023.kicad_pcb, ET-Abschlussgadget_2023.kicad_sch]
2023-04-07 Add rounded tracks
    [ET-Abschlussgadget_2023.kicad_pcb]
2023-04-14 Add copper to front, Improve sillkscreen
    [ET-Abschlussgadget_2023.kicad_pcb]
2023-04-14 Add qr code to silkscreen
    [ET-Abschlussgadget_2023.kicad_pcb]
2023-04-15 Add switch, Change qr to be smaller
    [ET-Abschlussgadget_2023.kicad_pcb, ET-Abschlussgadget_2023.kicad_sch]
2023-04-19 Add attiny programmer arduino
2023-04-24 Add material-list, Adjust footprints, add first datasheets
    [ET-Abschlussgadget_2023.kicad_pcb, ET-Abschlussgadget_2023.kicad_sch, Materialliste.xlsx]
2023-04-24 Redone whole layout based around new MCU, button and batteryholder-footprints are still placeholder tbd
    [ET-Abschlussgadget_2023-rounded.kicad_pcb, ET-Abschlussgadget_2023.kicad_sch]
2023-04-25 Changed button-footprint, moved resistors & capacitors from 0805 to 0603, minor tweaks
    [ET-Abschlussgadget_2023.kicad_pcb, ET-Abschlussgadget_2023.kicad_sch]
2023-04-25 Improve back silkscreen and routing
    [ET-Abschlussgadget_2023-rounded.kicad_pcb, ET-Abschlussgadget_2023.kicad_pcb]
2023-04-25 Add back copper pattern
    [ET-Abschlussgadget_2023.kicad_pcb]
2023-04-26 Updated switch & battery holder footprint, adjusted manual BOM
    [ET-Abschlussgadget_2023.kicad_pcb, ET-Abschlussgadget_2023.kicad_sch, Materialliste.xlsx]
2023-04-26 Move switch, Move testpads, Add spotify code
    [ET-Abschlussgadget_2023-rounded.kicad_pcb, ET-Abschlussgadget_2023.kicad_pcb]
2023-04-26 Improve back copper pattern
    [ET-Abschlussgadget_2023-rounded.kicad_pcb, ET-Abschlussgadget_2023.kicad_pcb]
2023-04-27 Fix spotify code
    [ET-Abschlussgadget_2023-rounded.kicad_pcb, ET-Abschlussgadget_2023.kicad_pcb]
2023-04-27 Generated Output-Files, Added LCSC-Partnumbers to schematic
    [ET-Abschlussgadget_2023-rounded-CmtUser.gbr, ET-Abschlussgadget_2023-rounded-CuBottom.gbl, ET-Abschlussgadget_2023-rounded-CuTop.gtl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]
2023-04-27 minor fixes
    [ET-Abschlussgadget_2023-rounded-CmtUser.gbr, ET-Abschlussgadget_2023-rounded-CuBottom.gbl, ET-Abschlussgadget_2023-rounded-CuTop.gtl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]
2023-04-27 updated materiallist
    [Materialliste.xlsx]
2023-04-27 Removed all designators, add silkscreen below MCU and LEDs
    [ET-Abschlussgadget_2023-rounded-CmtUser.gbr, ET-Abschlussgadget_2023-rounded-CuBottom.gbl, ET-Abschlussgadget_2023-rounded-CuTop.gtl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]
2023-04-28 Replaced all footprints exept 0603-resistor with LCSC-footprints, generated new production-files, replaced 0805-cap with 0603-cap inside materialliste
    [ET-Abschlussgadget_2023-rounded-CmtUser.gbr, ET-Abschlussgadget_2023-rounded-CuBottom.gbl, ET-Abschlussgadget_2023-rounded-CuTop.gtl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]
2023-04-28 Add led functions
2023-04-28 Fix firmware project file
    [main.c]
2023-05-02 Update TinyTouchLib, add code to main file, add debug code for PB0-pin
2023-05-05 updated pcbTest function, add tinytouch_init-function
2023-05-06 Update ir command to use hardware timer
2023-05-07 removed clk-pad from pcb, increased size of rothli-sticker, change IR-diode resistor from 590 to 220
    [ET-Abschlussgadget_2023.kicad_pcb, ET-Abschlussgadget_2023.kicad_sch]
2023-05-07 Add low pass filter, Update thresholds
2023-05-07 Add ground plane pattern to entire back side
    [ET-Abschlussgadget_2023-rounded.kicad_pcb, ET-Abschlussgadget_2023.kicad_pcb, ET-Abschlussgadget_2023.kicad_sch]
2023-05-10 Updated schematic with MOSFET and pulldown resistors, changed footprint for IR-diode
    [ET-Abschlussgadget_2023.kicad_pcb, ET-Abschlussgadget_2023.kicad_sch]
2023-05-10 Remove pulldown, Update resistors, Update routing
    [ET-Abschlussgadget_2023-rounded.kicad_pcb, ET-Abschlussgadget_2023.kicad_pcb, ET-Abschlussgadget_2023.kicad_sch]
2023-05-11 Replaced parts in materialliste, replaced some footprints, generade production-files with JLC-plugin
    [ET-Abschlussgadget_2023-rounded.kicad_pcb, ET-Abschlussgadget_2023.kicad_pcb, ET-Abschlussgadget_2023.kicad_sch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]
2023-05-11 Final export
    [ET-Abschlussgadget_2023-rounded-CmtUser.gbr, ET-Abschlussgadget_2023-rounded-CuBottom.gbl, ET-Abschlussgadget_2023-rounded-CuTop.gtl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]
2023-05-27 Fix capacitive touch using wrong pin
    [TinyTouchLib.c, TinyTouchLib.h]
2023-06-01 Renamed hardware-folder; add correct datasheets; updated materialliste.xlsx
    [ET-Abschlussgadget_2023-rounded.kicad_pcb, ET-Abschlussgadget_2023.kicad_pcb, ET-Abschlussgadget_2023.kicad_sch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]
